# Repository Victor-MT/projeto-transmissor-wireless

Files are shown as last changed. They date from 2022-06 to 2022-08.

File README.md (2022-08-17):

# Projeto Transmissor Wireless

### Sobre o projeto

O projeto em questão foi desenvolvido  com intuito de resolver um desafio proposto em um processo seletivo. A proposta é comunicar dois dispositivos utilizando tecnologia sem fio ou "wireless".
 
Considerando todos os aspectos  do desenvolvimento de uma solução tecnológica, o projeto foi dividido em etapas como definição de requisitos, desenvolvimento de hardware, software e produto final. Todas essas fases, embora pareçam seguir uma ordem em cadeia, foram desenvolvidas de forma iterativa e isso resultou em uma solução que atende todos requisitos solicitados. 

### Sumário
- [Definição de Requisitos](https://github.com/Victor-MT/projeto-transmissor-wireless#defini%C3%A7%C3%A3o-de-requisitos)
- [Arquitetura](https://github.com/Victor-MT/projeto-transmissor-wireless#arquitetura)
- [Hardware](https://github.com/Victor-MT/projeto-transmissor-wireless#hardware)
- [Firmware](https://github.com/Victor-MT/projeto-transmissor-wireless#firmware)
- [Produto Final](https://github.com/Victor-MT/projeto-transmissor-wireless#produto-final)
- [Conclusão](https://github.com/Victor-MT/projeto-transmissor-wireless#conclus%C3%A3o)
- [Referências](https://github.com/Victor-MT/projeto-transmissor-wireless#refer%C3%AAncias)

## |Definição de Requisitos
Os requisitos definidos pelo cliente, nesse caso, o documento de especificação do projeto, foram: 
- Comunicar dois dispositivos, usando uma arquitetura integralmente sem fio em um range de 100 metros em espaço aberto. 
- Enviar um arquivo de 500kB 
- Componentes utilizados de fácil acesso ( disponíveis no mercado)
- Interface simples de operar 
- Pelo menos um dispositivo utilizando bateria
- Pensar na case do dispositivos (produto final) 

#### Ferramentas utilizadas :
Arduino IDE, KiCad software

## |Arquitetura
Para essa primeira versão que tem como fim uma prova de conceito (POC), a arquitetura escolhida para esse projeto foi, basicamente, um microcontrolador conectado a um transmissor e um microcontrolador conectado a um receptor com a possibilidade de enviar as informações recebidas para outro dispositivo via serial. Essa arquitetura corresponde ao tipo de comunicação simplex com um transmissor e um receptor.

#### Arquitetura proposta

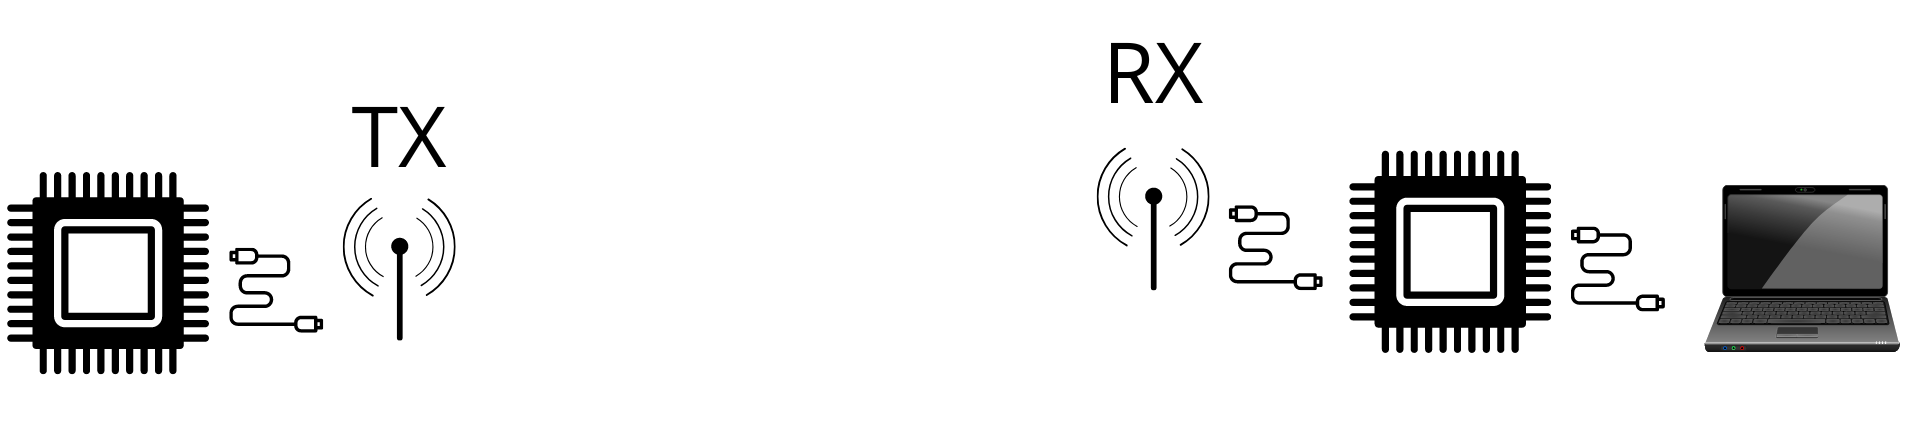
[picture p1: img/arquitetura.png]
Arquitetura


## |Hardware
Baseado na premissa da disponibilidade de mercado, foi selecionado como microcontrolador o arduino nano (chip ATMega328P) e o transmissor nRF24L01 por sua alta disponibilidade e preços relativamente baixos. Segundo o próprio [datasheet](https://www.alldatasheet.com/datasheet-pdf/pdf/1243924/ETC1/NRF24L01.html) do nRF24L01, ele possui um alcance de 100m em espaços abertos, sendo assim, atende ao principal requisito do projeto. Além disso, o transceptor em questão posssui mais 1 canal para se comunicar o que permite comunicações full-duplex. 

#### Arduino | NRF24 spec
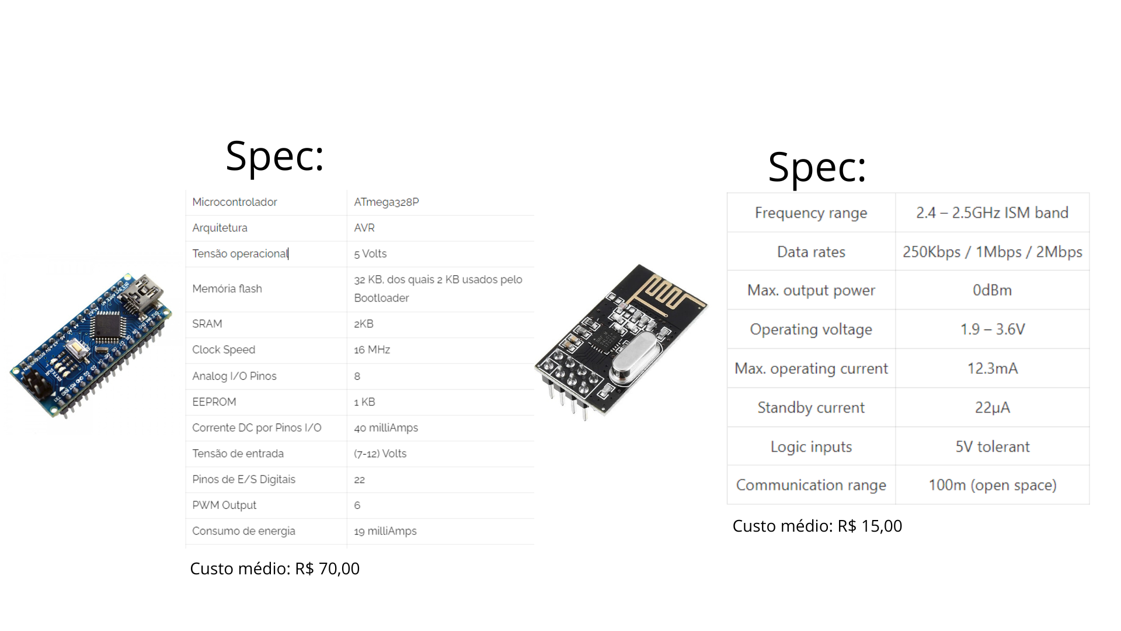
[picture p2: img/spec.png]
spec


Com esses dois dispositivos escolhidos foi possível desenvolver o esquemático do sistema e a consequentemente a placa pcb.

#### Esquemático
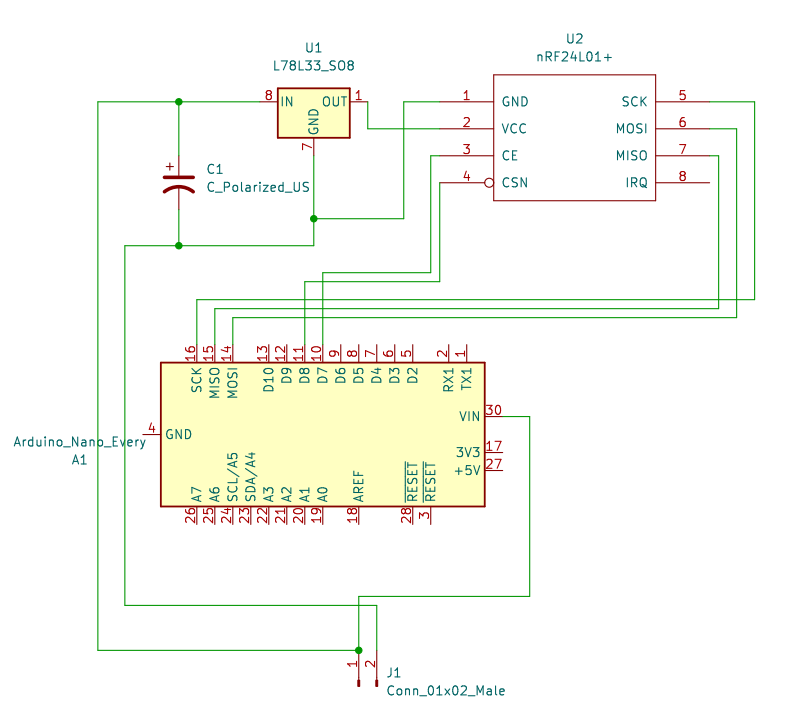
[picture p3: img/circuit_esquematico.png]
Eschm


Para o desenvolvimento da placa PCB foi utilizado o software KiCad.

#### PCB
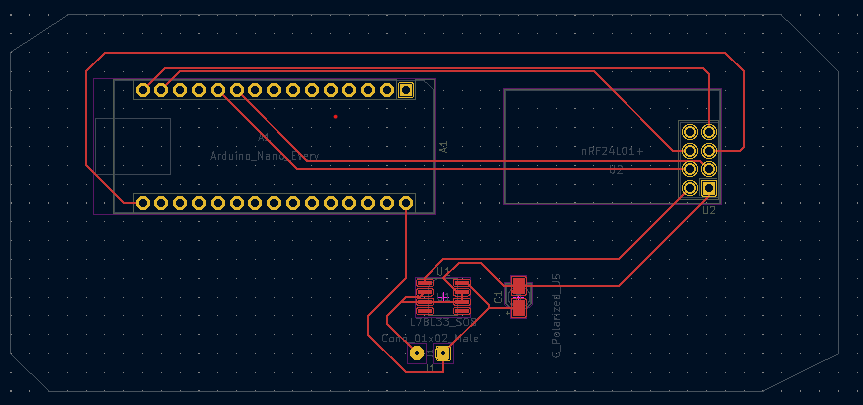
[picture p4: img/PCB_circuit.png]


[Formato da placa já desenvolvido para encaixar na case do protótipo.](https://github.com/Victor-MT/projeto-transmissor-wireless#produto-final)

#### PCB 3D
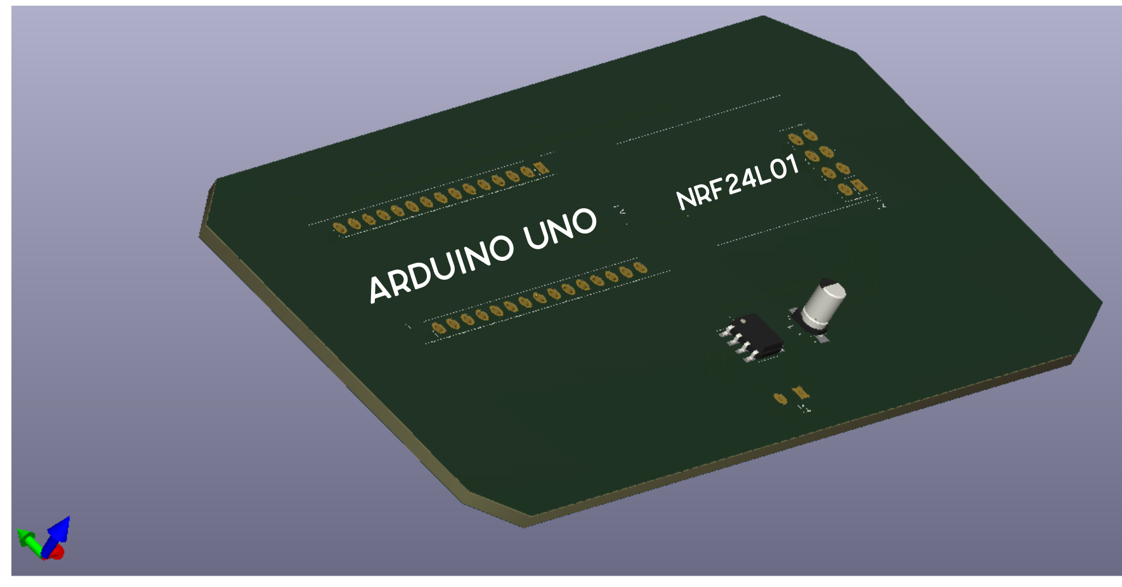
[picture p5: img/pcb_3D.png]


Coloquei os nomes dos dispositivos na placa 3D pois o KiCad não possui o modelo 3D dos componentes em questão, apenas as medidadas de referência. 

No caso acima para facilitar a configuração da placa e também deixar o protótipo aberto a futuras intervenções, foi utilizado a placa arduino nano e o módulo nRF24L01, porém durante o processo de confecção do produto real ambos podem ser substituídos por apenas o chip de cada módulo com apenas um circuito de proteção e assim diminuir ainda mais o custo do projeto.

A bateria do sistema foi escolhida baseada no consumo do mesmo que foi calculado em 31.3 mA. A bateria sugerida seria uma de 9V 250mAh ([bateria](https://www.amazon.com.br/Bateria-Recarreg%C3%A1vel-Blister-Elgin-Baterias/dp/B0754DF568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) e [conector](https://produto.mercadolivre.com.br/MLB-2114848124-clip-para-bateria-9v-capa-de-proteco-arduino-esp-nodemcu-_JM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)) e com isso a autonomia do projeto seria de aproximadamente 8 horas. 

## |Firmware
Para o desenvolvimento do firmware, por se tratar de dois dispositivos muito utilizados para prototipagem possuem diversas bibliotecas disponíveis, escolhemos utilizar a RF24, desenvolvida por [TMRh20](https://github.com/tmrh20/RF24/) que pode ser encontrada diretamente pelo gerenciador de bibliotecas na IDE do Arduino. 

No desenvolvimento  do firmware o principal desafio foi conseguir transportar um arquivo tão grande quanto 500kB já que a limitação do nRF24L01 é de 32 bytes por mensagem. Para solucionar o problema, o algoritmo desenvolvido divide a mensagem original em pequenos pedaços de 32 bytes de tamanho e depois o firmware do receptor remonta a mensagem. 

[Código do transmissor](https://github.com/Victor-MT/projeto-transmissor-wireless/tree/master/src/firmware/transmistter)
[Código do Receptor](https://github.com/Victor-MT/projeto-transmissor-wireless/tree/master/src/firmware/receiver)
## |Produto Final
Após a confecção da placa, foi desenvolvida uma case para proteger o sistema e tornar o produto mais apresentável para o cliente final poder manusear e acoplar onde for necessário. O formato octogonal foi escolhido por sua facilidade de encaixe em diversas posições e baixa complexidade de confecção, além de ser um formato agradável visualmente. 

#### Case
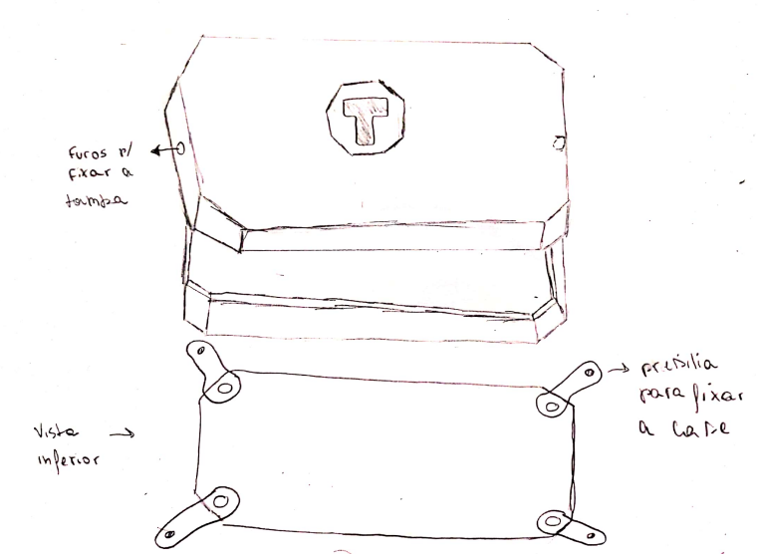
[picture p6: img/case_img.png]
case


## |Conclusão
Após todas essas etapas, podemos concluir que todos requisitos foram cumpridos resultando em um produto de fácil confecção, acessível no mercado e de simples operação. Segue abaixo o custo relativo ao projeto, sem considerar o custo para produção da PCB nem fabricação da case que deperiam do fornecedor já que seriam personalizadas.

#### Custo do projeto
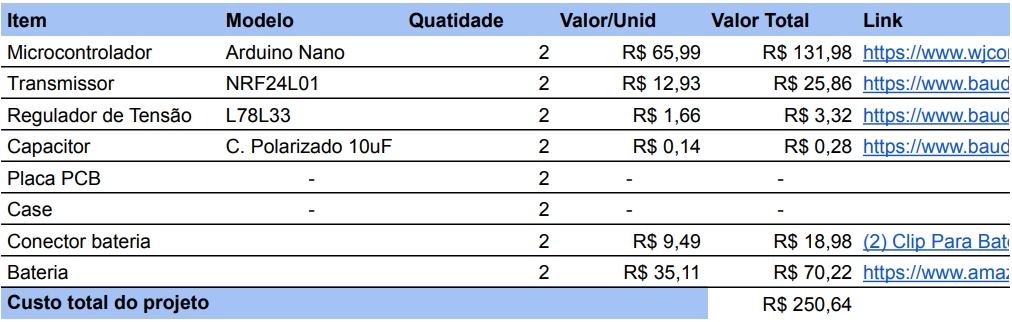
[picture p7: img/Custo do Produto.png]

[Planilha de custos](https://github.com/Victor-MT/projeto-transmissor-wireless/tree/master/src/product)

### Melhorias

Este projeto teve o instituto de prototipar um sistema de comunicação wireless em uma semana, sendo assim, é evidente que ficam pendentes diversas melhorias que poderiam ser implementadas. Deixarei aqui algumas sugestões.

#### Upgrades Futuros: 
- Indicador LED alertando por código de cor se a mensagem foi enviada e/ou recebida;
- Mudança de protocolo para full-duplex;
- Melhoria do firmware para feedback de resposta sobre a integridade da mensagem enviada pelo transmissor;
- Interface desktop para ler e exibir informações do receptor;
## |Referências

 - [Understanding Wireless Range Calculations](https://www.electronicdesign.com/technologies/communications/article/21796484/understanding-wireless-range-calculations)
 - [About nRF24L01](https://howtomechatronics.com/tutorials/arduino/arduino-wireless-communication-nrf24l01-tutorial/)
 - [Library Documentation](https://nrf24.github.io/RF24/)
 - [nRF24L01 datasheet](https://www.alldatasheet.com/datasheet-pdf/pdf/1243924/ETC1/NRF24L01.html)
 - [Modos de transmissão](https://www.canalti.com.br/redes-de-computadores/modos-de-transmissao-de-dados-simplex-half-duplex-full-duplex/)

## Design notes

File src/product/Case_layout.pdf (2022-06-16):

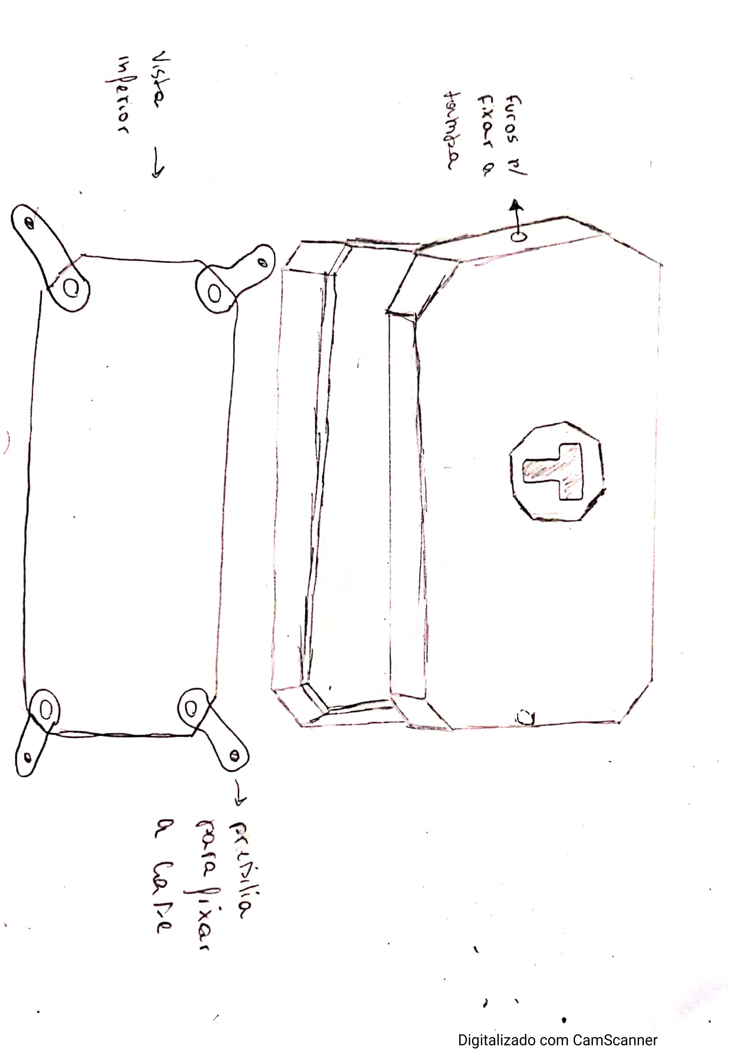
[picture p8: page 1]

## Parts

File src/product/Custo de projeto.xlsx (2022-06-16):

Item | Modelo | Quatidade | Valor/Unid | Valor Total | Link
Microcontrolador | Arduino Nano | 2 | R$65.99 | R$131.98 | https://www.wjcomponentes.com.br/arduino-nano-soldado?parceiro=6298 | 0
Transmissor | NRF24L01 | 2 | R$12.93 | R$25.86 | https://www.baudaeletronica.com.br/modulo-transceptor-wireless-2-4ghz-nrf24l01.html | 0
Regulador de Tensão | L78L33 | 2 | R$1.66 | R$3.32 | https://www.baudaeletronica.com.br/regulador-de-tensao-l78l33.html | 0
Capacitor | C. Polarizado 10uF | 2 | R$0.14 | R$0.28 | https://www.baudaeletronica.com.br/capacitor-eletrolitico-10uf-25v.html | 0
Placa PCB | - | 2 | - | -
Case | - | 2 | - | -
Conector bateria |  | 2 | R$9.49 | R$18.98 | (2) Clip Para Bateria 9v Capa De Proteção Arduino Esp Nodemcu | MercadoLivre (https://produto.mercadolivre.com.br/MLB-2114848124-clip-para-bateria-9v-capa-de-proteco-arduino-esp-nodemcu-_JM) | 0
Bateria |  | 2 | R$35.11 | R$70.22 | https://www.amazon.com.br/Bateria-Recarreg%C3%A1vel-Blister-Elgin-Baterias/dp/B0754DF568?hvadid=379726667452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 | 0
Custo total do projeto |  |  |  | R$250.64

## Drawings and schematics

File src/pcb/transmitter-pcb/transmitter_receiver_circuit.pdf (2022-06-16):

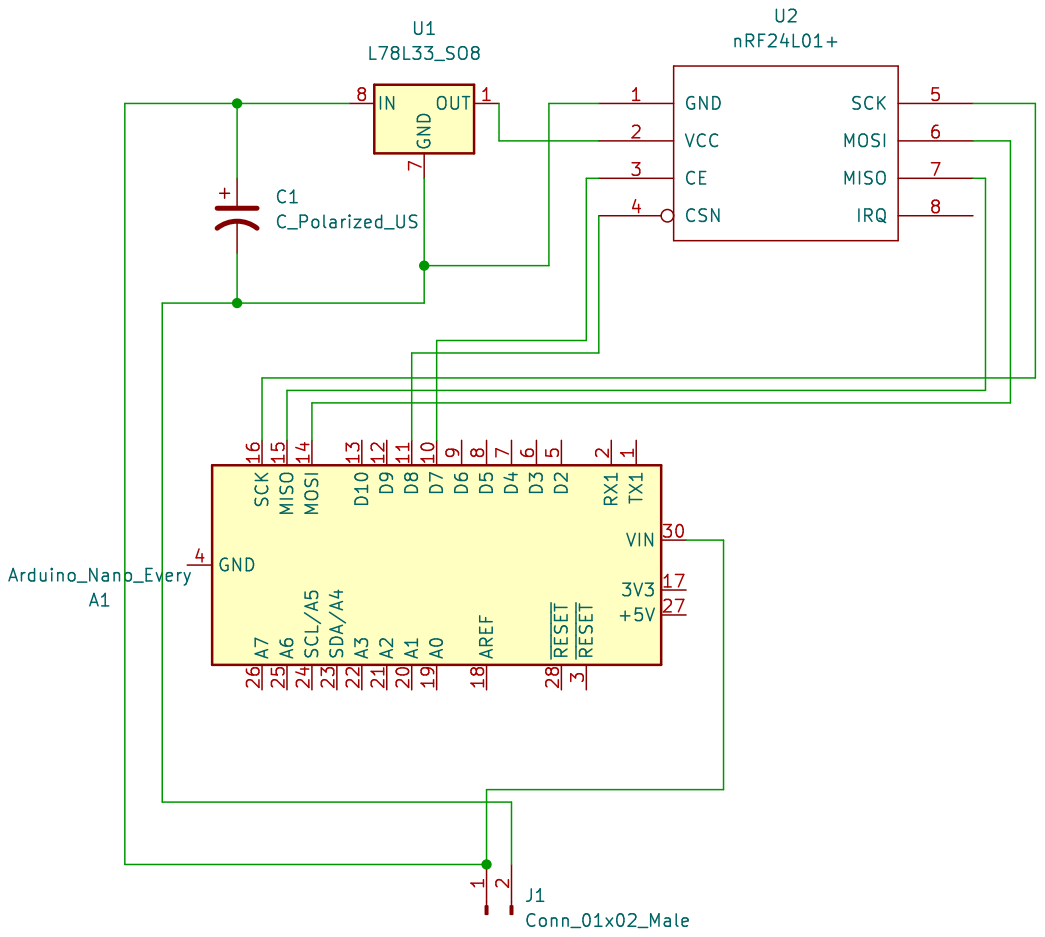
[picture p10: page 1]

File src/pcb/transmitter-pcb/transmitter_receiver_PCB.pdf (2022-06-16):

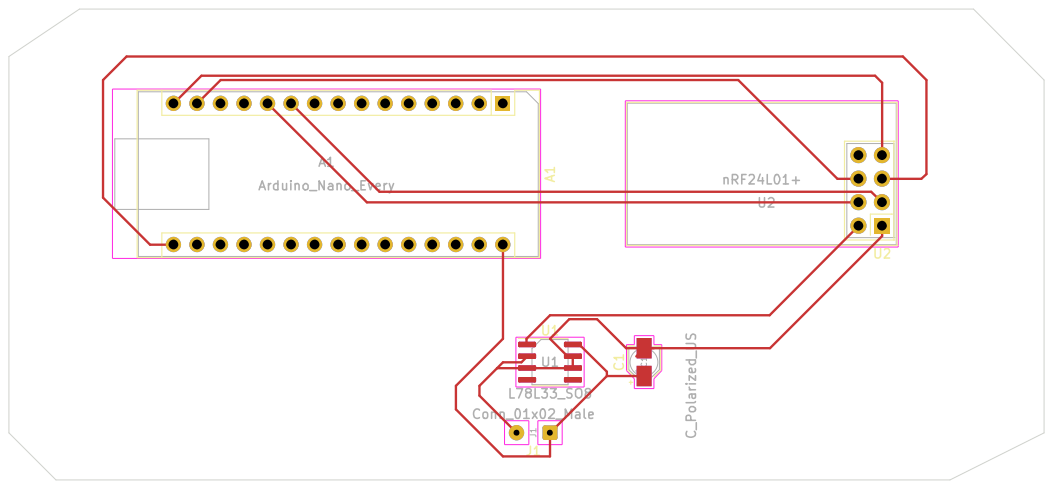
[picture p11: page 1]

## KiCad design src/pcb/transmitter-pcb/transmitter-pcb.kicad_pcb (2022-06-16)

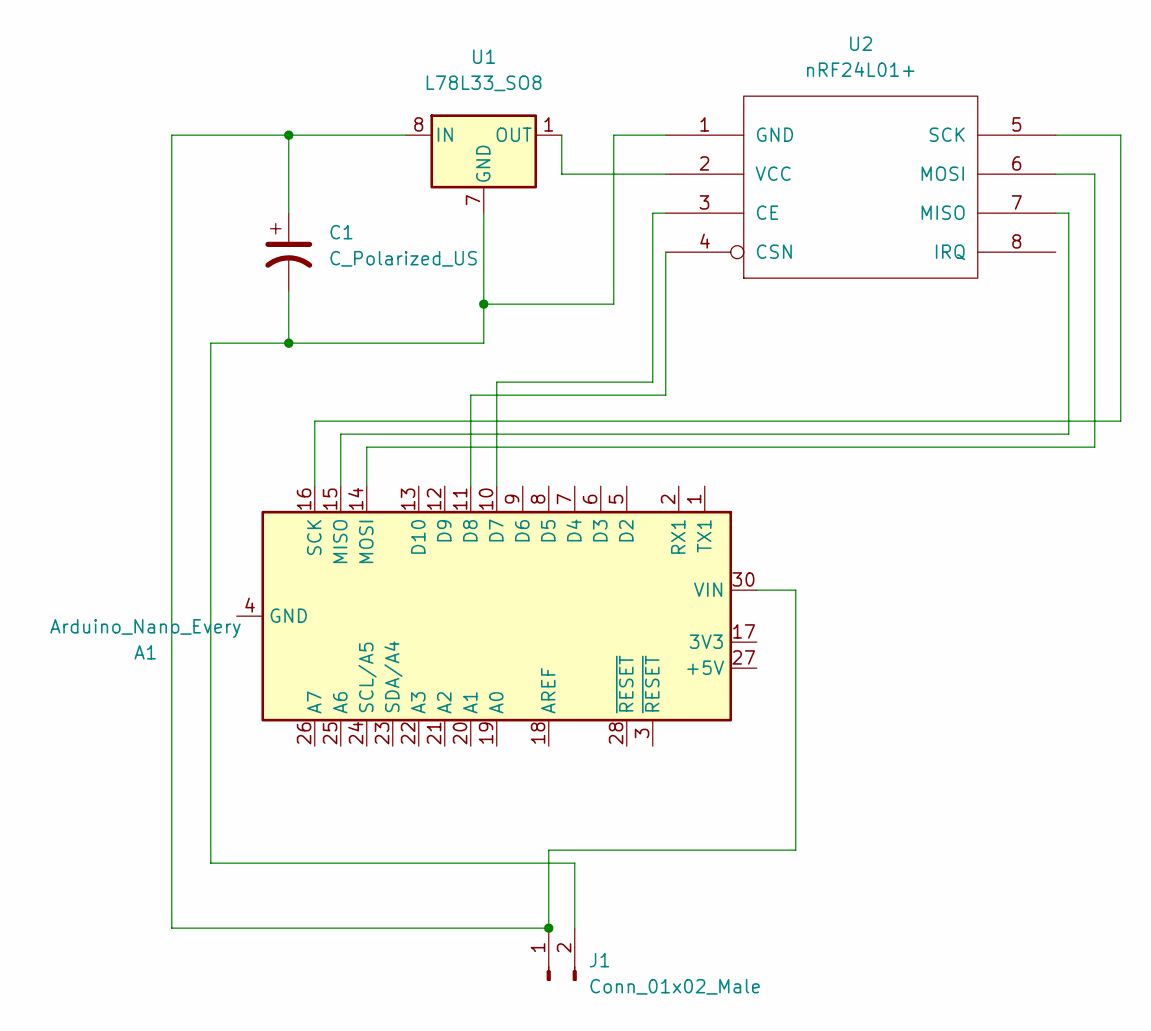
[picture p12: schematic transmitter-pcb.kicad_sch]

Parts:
A1: Arduino_Nano_Every; Arduino_Nano
C1: C_Polarized_US; CP_Elec_3x5.3
J1: Conn_01x02_Male; SolderWire-0.1sqmm_1x02_P3.6mm_D0.4mm_OD1mm
U1: L78L33_SO8; SOIC-8_3.9x4.9mm_P1.27mm
U2: nRF24L01+; nRF24L01_Breakout

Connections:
unnamed: A1.10 (D7), U2.3 (CE)
unnamed: A1.11 (D8), U2.4 (CSN)
unnamed: A1.14 (MOSI), U2.6 (MOSI)
unnamed: A1.15 (MISO), U2.7 (MISO)
unnamed: A1.16 (SCK), U2.5 (SCK)
unnamed: A1.4 (GND), A1.29 (GND)
unnamed: A1.30 (VIN), C1.1, J1.1, U1.8 (IN)
unnamed: C1.2, J1.2, U1.2 (GND), U1.3 (GND), U1.6 (GND), U1.7 (GND), U2.1 (GND)
unnamed: U1.1 (OUT), U2.2 (VCC)

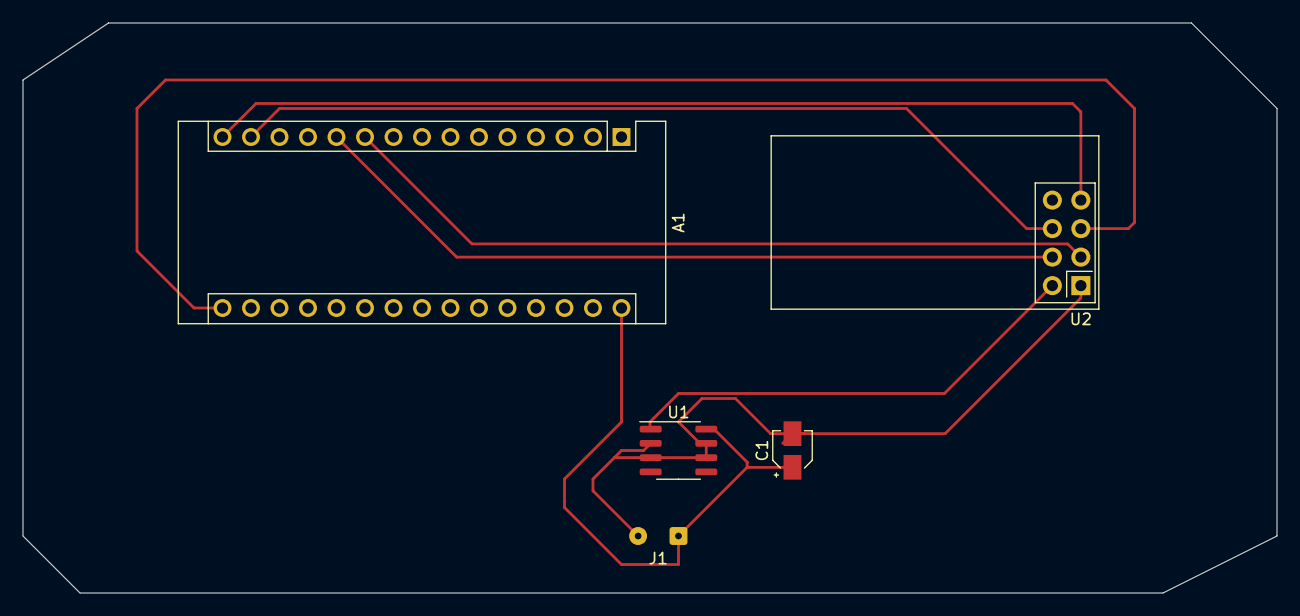
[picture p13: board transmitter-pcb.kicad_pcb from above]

Board: 2 copper layers, 111.8 x 50.8 mm, 5 parts (0 on the bottom side), 9 nets.

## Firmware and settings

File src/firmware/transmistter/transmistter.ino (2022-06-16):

/*
* Projeto Transmissor Wireless
*     Tractian Challenge
*                
* by Victor Hugo Martins Torres 
* 
* Library: TMRh20/RF24, https://github.com/tmrh20/RF24/
*/



/* ---------------------------- LIBRARY IMPORTATION ------------------------- */
#include <SPI.h>
#include <nRF24L01.h>
#include <RF24.h>
#include<string.h>

/* ----------------------- GLOBAL VARIABLES DECLARATION ------------------------ */
#define STR_MAX_LEN 32 // max message length for nrf24l01 transmitter
const char EndMessageSymbol[] = "#$#"; // End Message Symbol
RF24 radio(7, 8); // CE pin AND  CSN pin
const byte address[6] = "00001"; // channel address

/* 500kB message to be sent */
/*Random file character generator : https://onlinefiletools.com/generate-random-text-file  */
const String message = "assaasaasasasasasasaasasaassaasassasaasassaassaasassaassaassasassa";

/* ------------------------------- METHODS DECLARATION ------------------------ */
void sendMessage(String msg);

/* ------------------------------------ MAIN CODE --------------------------- */
void setup() {
  radio.begin();
  radio.openWritingPipe(address);
  radio.setPALevel(RF24_PA_MIN);
  radio.stopListening();
}

void loop() {
  sendMessage(message);
  delay(1000);
}

/*Due to data size limit of 32 bytes per message from the hardware specification. 
  This function will split the main message into small packages of 32 bytes and send them to Receiver*/
void sendMessage(String msg){
  for (unsigned i = 0; i < msg.length(); i += STR_MAX_LEN) {
    String subString = msg.substring(i, i + STR_MAX_LEN);
    char text[STR_MAX_LEN];
    subString.toCharArray(text, STR_MAX_LEN);
    
    radio.write(&text, sizeof(text));
    delay(10);
  }
  radio.write(&EndMessageSymbol, sizeof(EndMessageSymbol)); //to finish the communication, we send the end message symbol
}

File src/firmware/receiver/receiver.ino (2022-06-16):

/*
* Projeto Transmissor Wireless
*     Tractian Challenge
*                
* by Victor Hugo Martins Torres 
* 
* Library: TMRh20/RF24, https://github.com/tmrh20/RF24/
*/

/* ---------------------------- LIBRARY IMPORTATION ------------------------- */
#include <SPI.h>
#include <nRF24L01.h>
#include <RF24.h>
#include<string.h>

/* ----------------------- GLOBAL VARIABLES DECLARATION ------------------------ */
#define STR_MAX_LEN 32 // max message length for nrf24l01 transmitter
const byte address[6] = "00001"; // channel address
const char EndMessageSymbol[3] = "#$#"; // End Message Symbol
RF24 radio(7, 8); // CE pin AND  CSN pin

/* ------------------------------- METHODS DECLARATION ------------------------ */
String readTxMessage();
bool finishedTransmission(String msg);

/* ------------------------------------ MAIN CODE --------------------------- */
void setup() {
  Serial.begin(9600);
  radio.begin();
  radio.openReadingPipe(0, address);
  radio.setPALevel(RF24_PA_MIN);
  radio.startListening();
}

void loop() {
  String message;
  if (radio.available()) {
    Serial.println("STARTING READING MESSAGE...");
    message = readTxMessage();
  }
}

/* We need to get each piece of message sent (with size of 32 bytes) 
   and concatenate it to understand the full message */
String readTxMessage(){
  String message = "";
  char text[STR_MAX_LEN] = "";
  do{
    strcpy(text, "");
    radio.read(&text, sizeof(text));
    if(!finishedTransmission(EndMessageSymbol, text)){
      message.concat(String(text));
    }
  }while(finishedTransmission(EndMessageSymbol, text));
  
  Serial.println("MESSAGE RECEIVED...");
  Serial.println(message);
  Serial.println("#################### FINISHED TRANSMISSION ####################");
  return message;
}

/* Detect if the transmission was finished through the end message symbol*/
bool finishedTransmission(char *ems, char *msg){
  bool isFinished = false;
  int cmp;
  
  char str1[STR_MAX_LEN];
  char str2[STR_MAX_LEN];

  strcpy(str1, ems);
  strcpy(str2, msg);

  cmp = strcmp(str1, str2);
  
  if(cmp == 0){
    isFinished = true;
  }
  return isFinished;
}

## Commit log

2022-06-16 adding new info
    [transmitter-pcb-B_Cu.gbr, transmitter-pcb-B_Mask.gbr, transmitter-pcb-B_Paste.gbr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]
2022-06-16 case update
